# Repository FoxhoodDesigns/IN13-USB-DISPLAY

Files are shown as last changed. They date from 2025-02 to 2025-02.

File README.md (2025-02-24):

# IN13 USB Display
Designed as a companion to the Mini-Hardware-Monitor project ( https://github.com/FoxhoodDesigns/Mini-Hardware-Monitor ), a testbed for KiCad 9.0's new features and as a Evaluation project for the newer Microchip AVR DU Microcontrollers with USB interface

This project provides a trio of old Soviet-Era IN-13 Nixie Bargraphs that can be controlled via USB CDC communication. Both as an External display OR as a Internal display (case-mod).
The board is divided into 3 parts. 
+ The boost converter that provides ~180V to ignite the IN13 tubes
+ a set of three Voltage-controlled Current sinks to manipulate the strength of the signal to the tube based on the duty cycle of a PWM input
+ A AVR64DU32 Microcontroller handling USB-communication, PWM output and potential Sensor interface via QWIIC/STEMMA-QT interface.

# Current Status
Figuring out how to set the AVR64DU as CDC USB device via Microchip MCC kit. Once done the PCB's can be sent out.

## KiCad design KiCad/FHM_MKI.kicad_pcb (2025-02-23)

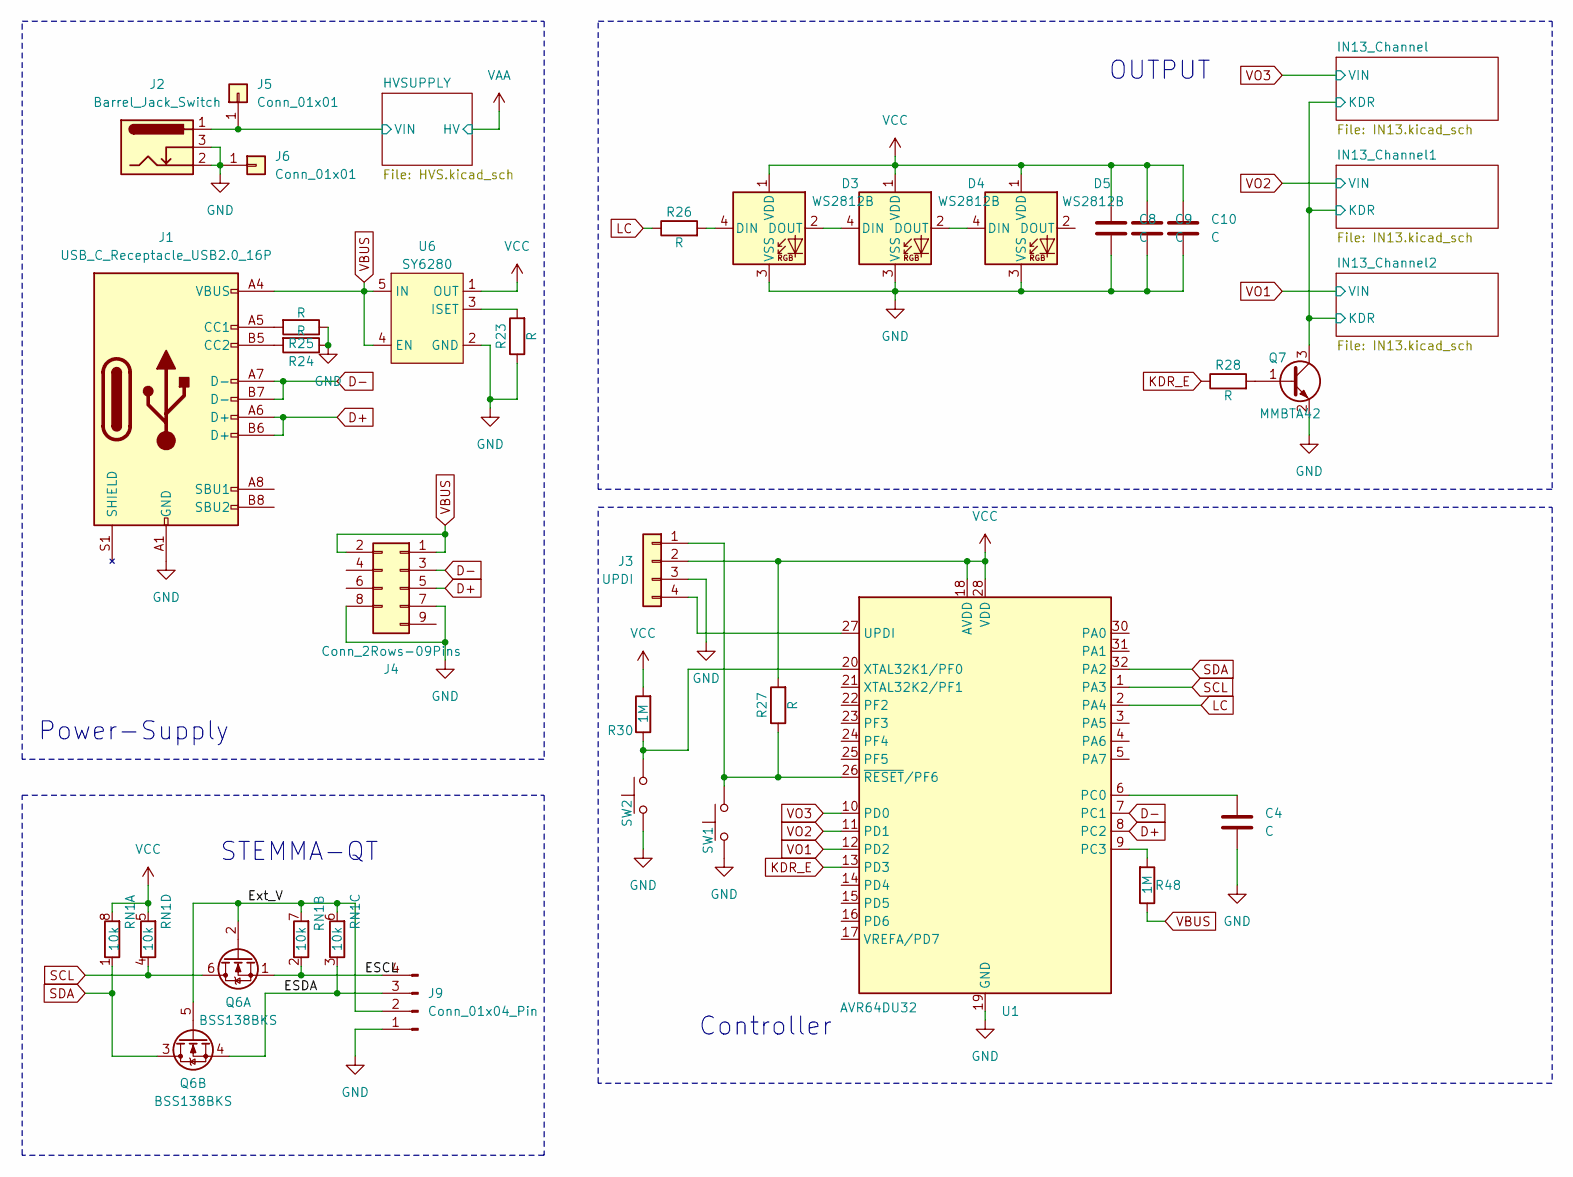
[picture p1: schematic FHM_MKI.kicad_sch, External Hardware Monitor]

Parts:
C4, C8, C9, C10: C; C_0805_2012Metric
D3, D4, D5: WS2812B; LED_WS2812B_PLCC4_5.0x5.0mm_P3.2mm
J1: USB_C_Receptacle_USB2.0_16P; USB_C_Receptacle_UJ20-C-V-C-3-SMT-TR_TopMnt_Vertical
J2: Barrel_Jack_Switch; BarrelJack_CUI_PJ-006A_Vertical
J3: UPDI; PinHeader_1x04_P2.54mm_Vertical_SMD_Pin1Left
J4: Conn_2Rows-09Pins; PinHeader_2x05_P2.54mm_Vertical_SMD
J5, J6: Conn_01x01; SolderWirePad_1x01_SMD_1x2mm
J9: Conn_01x04_Pin; JST_SH_BM04B-SRSS-TB_1x04-1MP_P1.00mm_Vertical
Q6: BSS138BKS; SOT-363_SC-70-6_Handsoldering
Q7: MMBTA42; SOT-23
R23, R24, R25, R26, R27, R28: R; R_0805_2012Metric
R30, R48: 1M; R_0805_2012Metric_Pad1.20x1.40mm_HandSolder
RN1: 10k; R_Array_Convex_4x0603
SW1, SW2: PTH_RA_7.4x4.3mm; SW_Push_1P1T_NO_Vertical_Wuerth_434133025816
U1: AVR64DU32; TQFP-32_7x7mm_P0.8mm
U6: SY6280; SOT-23-5_HandSoldering

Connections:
/ESCL: J9.4, Q6.1 (S), RN1.2 (R2.1)
/ESDA: J9.3, Q6.4 (S), RN1.3 (R3.1)
/Ext_V: J9.2, Q6.2 (G), Q6.5 (G), RN1.6 (R3.2), RN1.7 (R2.2)
/HVSUPPLY/VIN: J2.1, J5.1; also elsewhere on the board
/IN13_Channel/KDR: Q7.3 (C); also elsewhere on the board
D+: J1.A6 (D+), J1.B6 (D+), J4.5, U1.8 (PC2)
D-: J1.A7 (D-), J1.B7 (D-), J4.3, U1.7 (PC1)
GND: C4.2, C8.2, C9.2, C10.2, D3.3 (VSS), D4.3 (VSS), D5.3 (VSS), J1.A1 (GND), J1.A12 (GND), J1.B1 (GND), J1.B12 (GND), J2.2, J2.3, J3.3, J4.7, J4.8, J6.1, J9.1, Q7.2 (E), R23.1, R24.1, R25.1, SW1.1, SW2.1, U1.19 (GND), U1.29 (GND), U6.2 (GND); also elsewhere on the board
KDR_E: R28.1, U1.13 (PD3)
LC: R26.1, U1.2 (PA4)
unnamed: D3.4 (DIN), R26.2
unnamed: D3.2 (DOUT), D4.4 (DIN)
unnamed: D4.2 (DOUT), D5.4 (DIN)
unnamed: J1.A5 (CC1), R25.2
unnamed: J1.B5 (CC2), R24.2
unnamed: J3.1, R27.1, SW1.2, U1.26 (~RESET/PF6)
unnamed: J3.4, U1.27 (UPDI)
unnamed: Q7.1 (B), R28.2
unnamed: C4.1, U1.6 (PC0)
unnamed: R48.2, U1.9 (PC3)
unnamed: R30.1, SW2.2, U1.20 (XTAL32K1/PF0)
unnamed: R23.2, U6.3 (ISET)
SCL: Q6.6 (D), RN1.4 (R4.1), U1.1 (PA3)
SDA: Q6.3 (D), RN1.1 (R1.1), U1.32 (PA2)
VBUS: J1.A4 (VBUS), J1.A9 (VBUS), J1.B4 (VBUS), J1.B9 (VBUS), J4.1, J4.2, R48.1, U6.4 (EN), U6.5 (IN)
VCC: C8.1, C9.1, C10.1, D3.1 (VDD), D4.1 (VDD), D5.1 (VDD), J3.2, R27.2, R30.2, RN1.5 (R4.2), RN1.8 (R1.2), U1.18 (AVDD), U1.28 (VDD), U6.1 (OUT); also elsewhere on the board
VO1: U1.12 (PD2); also elsewhere on the board
VO2: U1.11 (PD1); also elsewhere on the board
VO3: U1.10 (PD0); also elsewhere on the board

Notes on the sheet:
Controller
Power-Supply
STEMMA-QT
OUTPUT

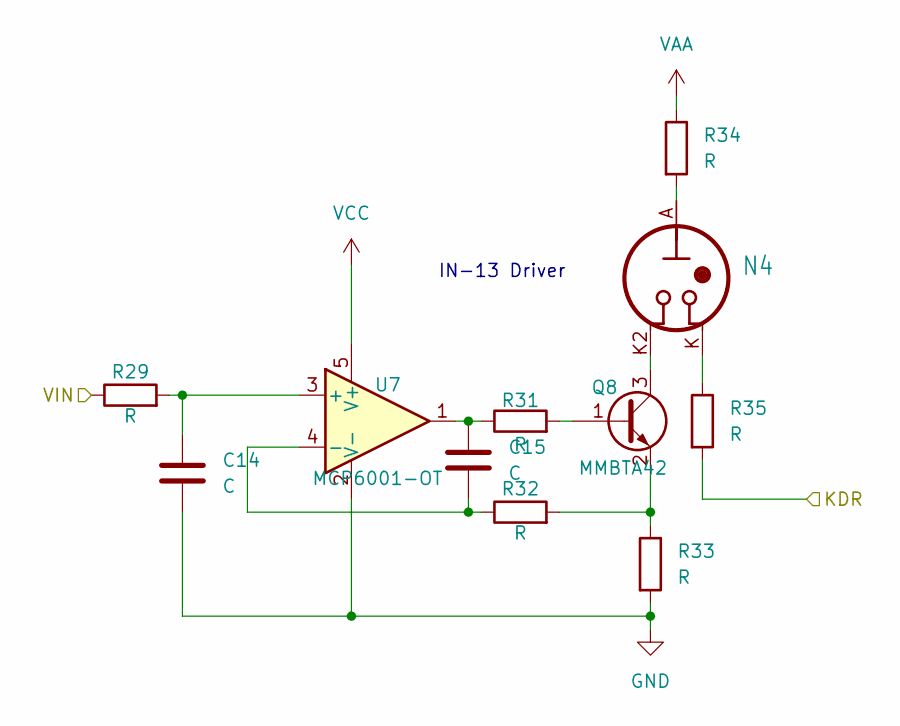
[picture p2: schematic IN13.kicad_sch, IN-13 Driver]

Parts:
C14, C15: C; C_0805_2012Metric
N4: IN-13
Q8: MMBTA42; SOT-23
R29, R31, R32: R; R_0805_2012Metric
R33, R35: R; R_0805_2012Metric_Pad1.20x1.40mm_HandSolder
R34: R; R_2512_6332Metric_Pad1.40x3.35mm_HandSolder
U7: MCP6001-OT; SOT-23-5

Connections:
/IN13_Channel/KDR: R35.2; also elsewhere on the board
GND: C14.2, R33.2, U7.2 (V-); also elsewhere on the board
unnamed: C15.1, R31.1, U7.1
unnamed: N4.A, R34.2
unnamed: N4.K, R35.1
unnamed: Q8.1 (B), R31.2
unnamed: N4.K2, Q8.3 (C)
unnamed: Q8.2 (E), R32.2, R33.1
unnamed: C14.1, R29.2, U7.3 (+)
unnamed: C15.2, R32.1, U7.4 (-)
VAA: R34.1; also elsewhere on the board
VCC: U7.5 (V+); also elsewhere on the board
VO3: R29.1; also elsewhere on the board

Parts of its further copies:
C16, C17, C18, C19: C; C_0805_2012Metric
N5, N6: IN-13
Q9, Q10: MMBTA42; SOT-23
R36, R37, R38, R42, R43, R44: R; R_0805_2012Metric
R39, R41, R45, R47: R; R_0805_2012Metric_Pad1.20x1.40mm_HandSolder
R40, R46: R; R_2512_6332Metric_Pad1.40x3.35mm_HandSolder
U8, U9: MCP6001-OT; SOT-23-5

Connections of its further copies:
/IN13_Channel/KDR: R41.2, R47.2; also elsewhere on the board
GND: C16.2, C18.2, R39.2, R45.2, U8.2 (V-), U9.2 (V-); also elsewhere on the board
unnamed: C17.1, R37.1, U8.1
unnamed: C19.1, R43.1, U9.1
unnamed: N5.A, R40.2
unnamed: N5.K, R41.1
unnamed: N6.A, R46.2
unnamed: N6.K, R47.1
unnamed: Q9.1 (B), R37.2
unnamed: N5.K2, Q9.3 (C)
unnamed: Q9.2 (E), R38.2, R39.1
unnamed: Q10.1 (B), R43.2
unnamed: N6.K2, Q10.3 (C)
unnamed: Q10.2 (E), R44.2, R45.1
unnamed: C16.1, R36.2, U8.3 (+)
unnamed: C17.2, R38.1, U8.4 (-)
unnamed: C18.1, R42.2, U9.3 (+)
unnamed: C19.2, R44.1, U9.4 (-)
VAA: R40.1, R46.1; also elsewhere on the board
VCC: U8.5 (V+), U9.5 (V+); also elsewhere on the board
VO1: R42.1; also elsewhere on the board
VO2: R36.1; also elsewhere on the board

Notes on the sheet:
IN-13 Driver

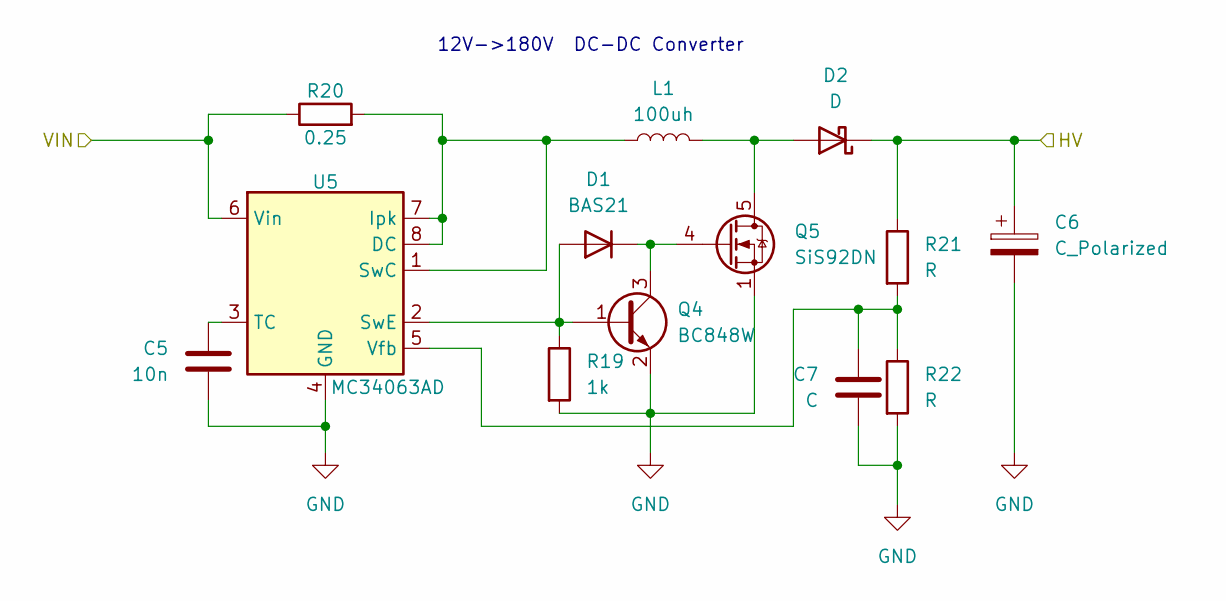
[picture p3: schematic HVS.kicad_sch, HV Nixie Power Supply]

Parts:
C5: 10n; C_0805_2012Metric
C6: C_Polarized; CP_Elec_8x11.9
C7: C; C_0805_2012Metric
D1: BAS21; SOT-23
D2: D; D_SMA
L1: 100uh; L_12x12mm_H8mm
Q4: BC848W; SOT-323_SC-70
Q5: SiS92DN; Vishay_PowerPAK_1212-8_Single
R19: 1k; C_0805_2012Metric_Pad1.18x1.45mm_HandSolder
R20: 0.25; R_2512_6332Metric_Pad1.40x3.35mm_HandSolder
R21, R22: R; C_0805_2012Metric_Pad1.18x1.45mm_HandSolder
U5: MC34063AD; SOIC-8_3.9x4.9mm_P1.27mm

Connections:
/HVSUPPLY/VIN: R20.1, U5.6 (Vin); also elsewhere on the board
GND: C5.2, C6.2, C7.2, Q4.2 (E), Q5.1 (S), Q5.2 (S), Q5.3 (S), R19.2, R22.2, U5.4 (GND); also elsewhere on the board
unnamed: D1.1 (A), Q4.1 (B), R19.1, U5.2 (SwE)
unnamed: D1.3 (K), Q4.3 (C), Q5.4 (G)
unnamed: D2.2 (A), L1.2, Q5.5 (D)
unnamed: L1.1, R20.2, U5.1 (SwC), U5.7 (Ipk), U5.8 (DC)
unnamed: C5.1, U5.3 (TC)
unnamed: C7.1, R21.2, R22.1, U5.5 (Vfb)
VAA: C6.1, D2.1 (K), R21.1; also elsewhere on the board

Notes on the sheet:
12V->180V DC-DC Converter

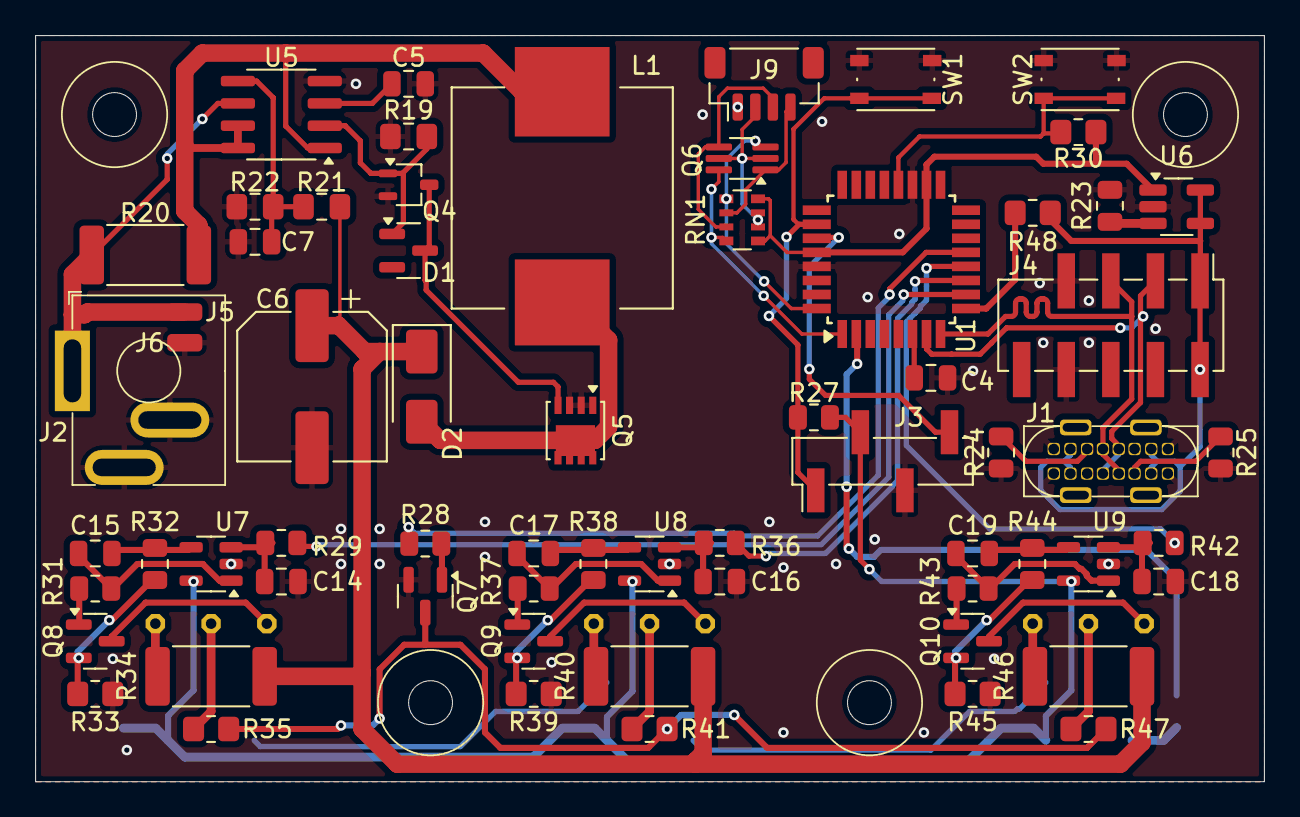
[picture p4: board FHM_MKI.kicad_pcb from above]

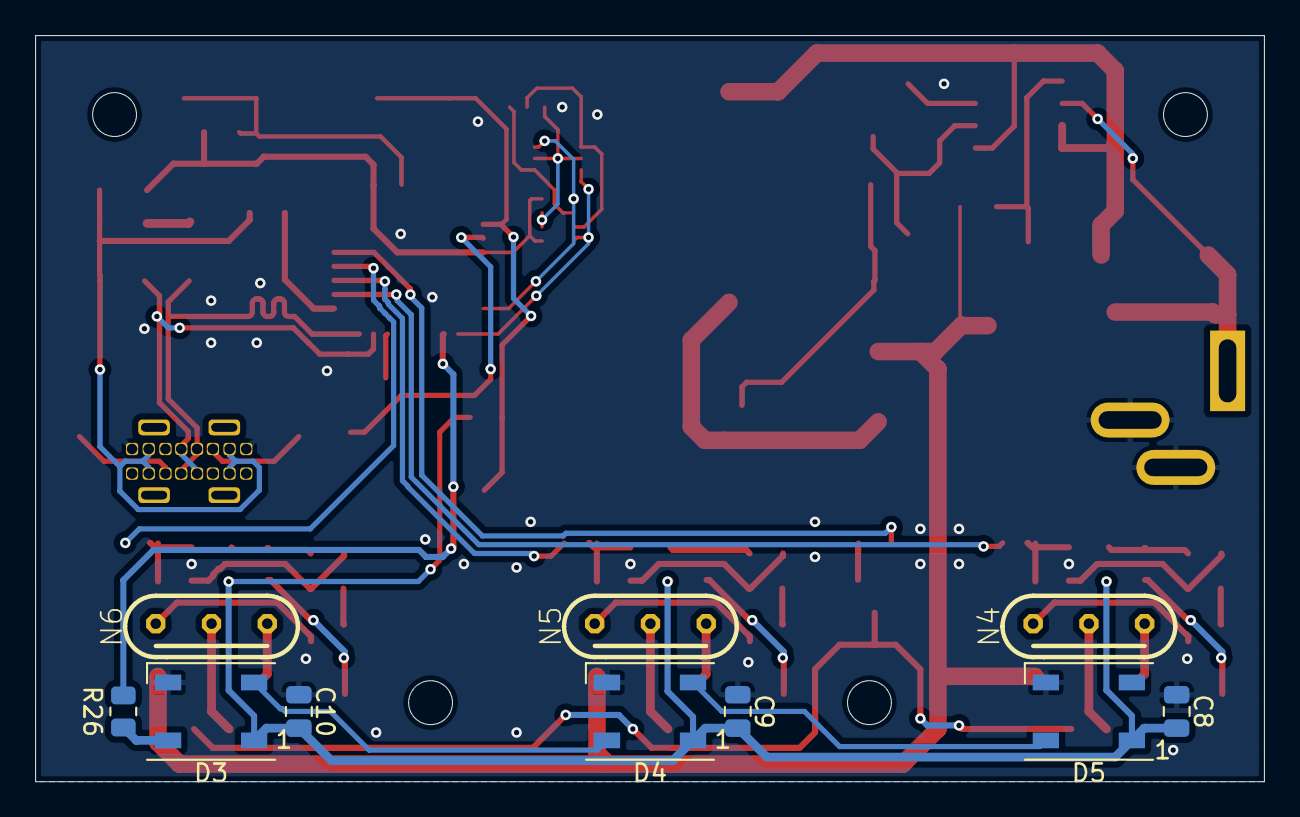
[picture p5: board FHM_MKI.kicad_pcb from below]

Board: 2 copper layers, 70.0 x 42.5 mm, 75 parts (10 on the bottom side), 60 nets.
